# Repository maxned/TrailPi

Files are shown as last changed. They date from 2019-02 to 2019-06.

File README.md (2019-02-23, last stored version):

# TrailPi
ECS 193 Senior Design Project for a DIY Web Cameras Network

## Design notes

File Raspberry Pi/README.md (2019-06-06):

# README

This is the software that is meant to run on the Raspberry Pi.

For a release, save all of these files into a folder called **TrailPi** and zip it. This folder should be saved to the home directory on the Pi.

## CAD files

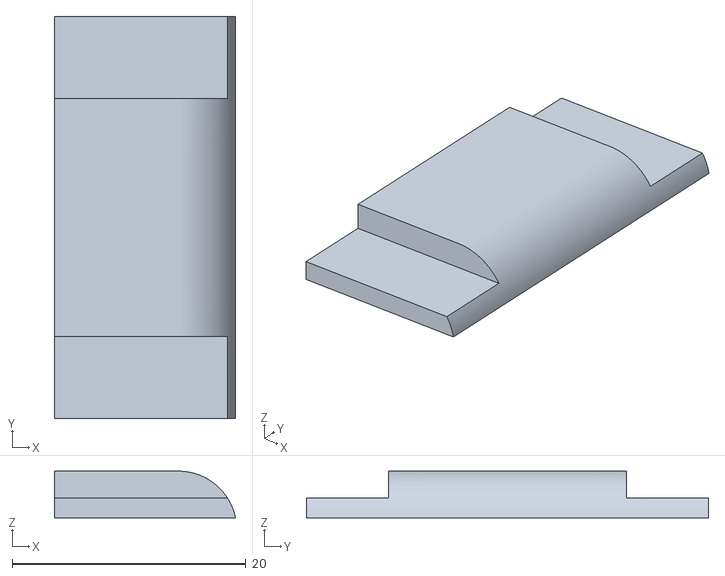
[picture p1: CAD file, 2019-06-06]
3D Printed Components/IR LED Endstop.stl
15.5 x 34.4 x 4.00

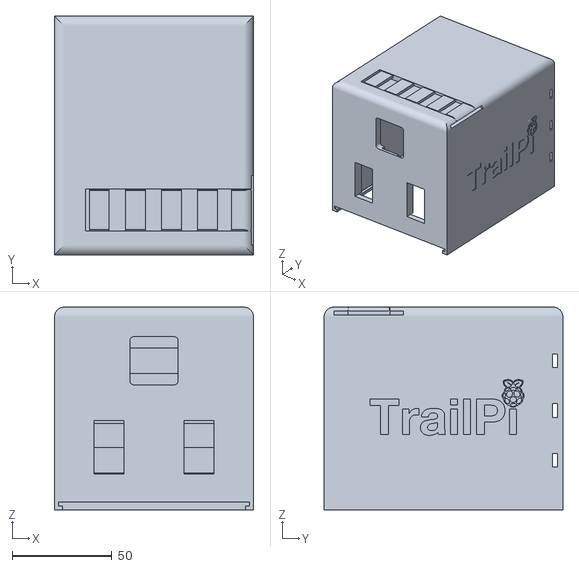
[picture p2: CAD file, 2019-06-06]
3D Printed Components/Enclosure.stl
100.0 x 120.0 x 102.0

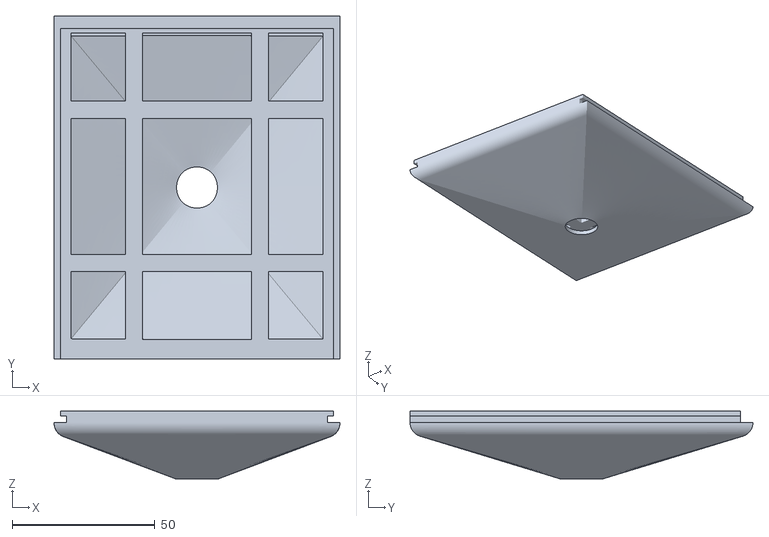
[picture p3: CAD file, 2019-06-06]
3D Printed Components/Bottom Cover.stl
100.0 x 120.0 x 23.7

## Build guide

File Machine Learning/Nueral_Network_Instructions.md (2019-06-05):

# TrailPi
ECS 193 Senior Design Project for a DIY Web Cameras Network

## Image recognition using a 5-layer CNN (Convolutional Neural Network)

### Requirements

To install packages that will work with the CNN model type into the terminal:

     $ pip install -r requirements.txt 

### **Running the Script**
The script used to run:

    $ python test.py

 The script will load in the model and then will ask the user if they want to apply the model on a folder or a single image :

    $ Folder(F) or Single File(S)?: _

### **Choosing Folder(F)**
1. If user selects folder, then the script will check locally if `animals_and_humans` and `nothing` folders already exists, if they don't then it will create them. Then the user is asked to enter the folder name (local to the script) of the images they want to classify:

    $ Folder Name: folder_name_here

2. Hit `Return` and the script will begin sorting the images into their respective folders (`animals_and_humans` or `nothing`).
3. Once complete, the prompt will ask if the user would like to continue and sort other files or folders with the following prompt:

        $ Continue (Y/N): _

4. If user selects `'N'` then the script will terminate, and if the user selects `'Y'` then the script will repeat the steps above asking if the user wants a folder or single file.

### **Choosing Single File(S)**
1. If the user selects single file, then the script will prompt the user to give the name of the image (must be local to the script) as such:

        $ ImageName: my_image.jpg 

2. The script will then print out if the image contains an animal/human or if there is nothing in the image.
3. Once complete, the prompt will ask if the user would like to continue and sort other files or folders with the following prompt:

        $ Continue (Y/N): _ 
4. If user selects `'N'` then the script will terminate, and if the user selects `'Y'` then the script will repeat the steps above asking if the user wants a folder or single file.

## **Retraining the Image Classifier**

1. Ensure that the **requirements** are installed before running the model.
2. Ensure that the script `cnn.py` has  `animals`, `nothing` and `people` folder local to it. The reason the `animals` and `people` folder are kept separate is in case the user may want to modify the classes to determine if its a person or animal instead. 
3. In  a terminal window run:

         $ python cnn.py

4. The script is now creating a new model with the provided images.
5. A `labels.npy` and `trail_pics.pny` file will be created, these are the numpy representation of the images, very useful if later the user decides to use the same images, the user would uncomment the following lines in the `cnn.py` file:

        trail_pics = np.load("trail_pics.npy")
        labels = np.load("labels.npy")
6. Once the neural network is done with it's training and validation, two files will  be created locally named `model.h5` (containing the weights for the model) and `model.json` (containing the actual model).
7. Replace the `model.h5` and `model.json` that are local to the `test.py` and `classifier.py` folder with the new ones generated.
8. The new model will now be used by the `test.py` to make predictions on new images.

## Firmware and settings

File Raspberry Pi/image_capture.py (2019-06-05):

# This script is in charge capturing images and saving them to disk.

# Basic method of operation:
# - Set everything up
# - Indefinitely run the image capture
# - Use signals to pause the image capture when necessary
# - Flags are used to specify what happens in the image capture loop based
#   on different events such as enabling/disabling capture or detected motion.

from picamera import PiCamera
from gpiozero import MotionSensor, DigitalOutputDevice
from datetime import datetime
import helpers
import json
import time
import signal
import io
import os

# Global variables set in main
log = None
config = None
pir_output = None
pir_input = None
relay_output = None
take_picture = False

def set_ir_led_state(state):
    relay_output.value = state
    log.info("IR state set: {}".format(state))

def take_picture(signum, frame):
    log.debug("Signal take picture")

    global take_picture
    take_picture = True

def enable_capture(signum, frame):
    log.info("Signal capture enabled")

    global capture_enabled
    capture_enabled = True

    # Turn on IR LED if it should be on now
    if config["ir_led_always_on"]:
        set_ir_led_state(True)

def disable_capture(signum, frame):
    log.info("Signal capture disabled")

    global capture_enabled
    capture_enabled = False

    # Always turn off LED
    set_ir_led_state(False)

def motion_detected():
    log.info("Motion detected: {}".format(pir_input.value))

    # Mirror the output of the PIR sensor for the other Pi
    pir_output.value = pir_input.value

    if pir_input.value and capture_enabled:
        global take_picture
        take_picture = True

        # If IR LED only on during capture then we need to turn it on
        # because an event just occured
        if not config["ir_led_always_on"]:
            set_ir_led_state(True)

def switch_to_other_camera():
    log.info("Switch to other camera")

    pid = helpers.get_pid("camera_manager.py")
    if pid == 0: # camera_manager isn't running for some reason
        log.warning("camera_manager.py PID not found")
        return

    # Signal to camera_manager.py that the night camera should be enabled and self
    # should be disabled
    os.kill(pid, signal.SIGUSR1)

def save_picture(image, timestamp):
    if image:
        try:
            # Make sure directory exists
            if not "images" in os.listdir():
                os.mkdir("images")

            with open('{}/{}.jpg'.format(config["image_folder"], timestamp), 'wb') as file:
                file.write(image)

                # Make sure file is saved to disk so it can be uploaded
                file.flush()
                os.fsync(file.fileno())

                log.info("Saved image: {}.jpg".format(timestamp))
        except:
            log.error("Failed saving image to disk: {}".format(timestamp))

def begin_image_capture():
    camera = PiCamera(resolution=tuple(config["resolution"]))
    # Encode the site number into the exif field of the image just in case
    camera.exif_tags["EXIF.SubjectDistanceRange"] = str(config["site_number"])
    time.sleep(2) # Give camera time to wake up

    # Goal is keep capturing images and saving images to a buffer
    # When told to take_picture, save the buffered images to disk
    # Then save the current image to disk and the same number of buffered images after

    # Images to save before and after take_picture event
    buffer_size = int(config["capture_chunk_size"] / 2)
    image_buffer = helpers.RingBuffer(buffer_size)
    left_to_save = 0

    stream = io.BytesIO()
    # Quality is not in percentage, it is logarithmic
    # Do not save the thumbnail to keep the file size smaller
    for capture in camera.capture_continuous(stream, format='jpeg',
                                             quality=config["quality"], thumbnail=None):

        log.info("Image Captured")
        log.info("Analog Gain: " + str(float(camera.analog_gain)))
        log.info("Digital Gain: " + str(float(camera.digital_gain)))

        # Timestamp the image
        timestamp = datetime.now().strftime(config["image_timestamp_format"])

        # Event happened so save buffered images and start saving future images
        global take_picture
        if take_picture == True:
            take_picture = False

            # Save buffered images to disk
            for image, im_timestamp in image_buffer.get():
                save_picture(image, im_timestamp)

            # Clear buffered images
            image_buffer.clear()

            # Number of images to save past the take_picture event
            # including the image right after the event
            left_to_save = buffer_size + 1

        if left_to_save > 0:
            # These are the images saved to disk after the take_picture event
            save_picture(stream.getvalue(), timestamp)
            left_to_save -= 1
        else:
            # Save images into buffer if not saving them to disk
            # Save as tuple together with the timestamp
            image_buffer.append((stream.getvalue(), timestamp))

            # If IR LED only on during capture then we are done so turn it off
            if not config["ir_led_always_on"]:
                set_ir_led_state(False)

        # Reset the stream to capture a new image
        stream.seek(0)
        stream.truncate()

        # Switch to the other camera based on the specified thresholds
        if config["camera_type"] == "day" and capture_enabled and \
                camera.analog_gain >= config["day_to_night_analog_threshold"] and \
                camera.digital_gain >= config["day_to_night_digital_threshold"]:
            switch_to_other_camera()
        elif config["camera_type"] == "night" and capture_enabled and \
                camera.analog_gain <= config["night_to_day_analog_threshold"] and \
                camera.digital_gain <= config["night_to_day_digital_threshold"]:
            switch_to_other_camera()

        # Sleep between images (needed to allow auto exposure to work)
        # Values of at least 0.1 will allow camera to expose within 10 seconds
        # Higher values will allow for faster exposure
        time.sleep(config["inter_capture_delay"])

        # If capture is disabled, stop taking pictures and suspend the whole script
        while not capture_enabled:
            signal.pause()

if __name__== "__main__":
    log = helpers.setup_logger(os.path.basename(__file__))
    log.info("Starting execution")

    if os.path.exists("/boot/trailpi_config.json"):
        config_file = "/boot/trailpi_config.json"
    else:
        config_file = "trailpi_config.json"

    config = json.load(open(config_file))

    # Default value for whether image capture should be enabled on start
    # depending on camera_type (day or night)
    if config["camera_type"] == "day":
        capture_enabled = True
    else:
        capture_enabled = False

    # PIR output that mirrors PIR input for use by the other Pi
    pir_output = DigitalOutputDevice(config["pir_output_pin"])

    # PIR connected to GPIO pin
    pir_input = MotionSensor(config["pir_input_pin"])
    pir_input.when_motion = motion_detected
    pir_input.when_no_motion = motion_detected

    # Day camera will not have IR LED connected so we don't have to differentiate
    # turning on the relay between day and night camera with the IR LED
    relay_output = DigitalOutputDevice(config["relay_output_pin"])

    # Set default state of IR LED if it should always be on
    if config["ir_led_always_on"] and capture_enabled:
        set_ir_led_state(True)

    # Manually trigger a take_picture event (only for debug)
    if config["debug"]:
        signal.signal(signal.SIGINT, take_picture)

    # Sign up for signals to control whether capture should be enabled or disabled
    signal.signal(signal.SIGUSR1, enable_capture)
    signal.signal(signal.SIGUSR2, disable_capture)

    # Keep taking pictures but save them only when needed
    begin_image_capture()

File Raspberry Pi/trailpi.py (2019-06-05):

# This script is in charge of running and stopping all of the TrailPi scripts
# and relaunching them if something crashes.

import subprocess
import helpers
import time
import signal
import os

scripts = ["camera_manager.py", "image_capture.py", "image_upload.py", "check_in.py"]

# Kill all scripts including self (useful for debugging)
def kill_everything(signum, frame):
    for script in scripts:
        pid = helpers.get_pid(script)
        if pid != 0:
            os.kill(pid, signal.SIGKILL)
    raise

signal.signal(signal.SIGINT, kill_everything)

# Make sure directory for crashlogs exists
if not "crashlogs" in os.listdir():
    os.mkdir("crashlogs")

# Launch all of the scripts and relaunch them if they crash
while True:
    for script in scripts:
        pid = helpers.get_pid(script)

        # Restart script if it crashed or hasn't been started yet
        if pid == 0:
            ps = subprocess.Popen("python3 {} 2>crashlogs/{}.crashlog &".format(script, script), shell=True)

    # Recheck for crashed scripts every so often
    time.sleep(60)

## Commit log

2019-02-26 Simple server/client building blocks
    Starting scripts for both server and clients, believe client doesn't
    work currently, will be fixed and expanded upon
    <Add> 'client/TrailPiClient.py'
    <Add> 'server/TrailPiServer.py'
2019-02-27 Skeletons for server + client scripts
    Outline scripts for server and client, with functional communication
    Two modes for client connection:
    1) `check_in`, to show camera is active
    2) `new_image`, to transfer a new image to server
    Starts in a testing mode with lots of debugging output to follow steps
    Running:
    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
2019-02-28 Activity tracking implemented
    Server will now handle check-in requests, storing last check-in time in
    a dictionary and logging it in a file
    <Upd> 'client/TrailCamMain.py' - debug output for closing the socket
    <Upd> 'client/Mode1.py' - remove leftover filler message causing issues
    <Upd> 'server/TrailServerMain.py'
    - some changes to recv calls to fix timeout not working
    - utilize the activity tracking logic when appropriate
    - some *more* debugging output
    <Add> 'server/Living.py' - dictionary and function for maintaining the
    activity log
2019-03-01 Handle logging, specific exception, empty message
    Add function to log server requests to a file, target specific
    `socket.timeout` exception, fix the issue of the empty message being
    received.
    <Upd> 'client/Mode0.py' - change `socket.send` to `socket.sendall`
    <Upd> 'client/Mode1.py' - change `socket.send` to `socket.sendall`
    - change `socket.send` to `socket.sendall`
    - implement logging function and call it after getting requests
    - target timeout specific exception before general exceptions
    - more checking on received data and watching the socket
    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
2019-03-07 Use logging module instead of just print() calls
    Adjusted all files for this change
2019-03-12 Further transitioning to flask
    Move more to the flask server/client, also trimmed old code in all
    files
    <Upd> 'client/TrailCamMain' - this script doesn't do much currently
    <Upd> 'client/Mode0' - just sends post request
    <Upd> 'client/Mode1' - just sends post request with image file
    <Upd> 'server/TrailServerMain' - lots of logic added for new setup
    <Upd> 'server/Living' - clean up process
2019-03-13 Streamline files with better names
    No longer need separate files for client modes, provide cleaner api
    calls,
    <Rmv> 'client/Mode0.py' - merged into `client/camera_client_api.py`
    <Rmv> 'client/Mode1.py' - merged into `client/camera_client_api.py`
    <Upd> 'client/camera_client_api.py':
    - file renamed from `client/TrailCamMain`
    - provides api calls `check_in()` and `send_image(file_path)`
    <Upd> 'server/activity.py':
    - file renamed from `server/Living.py`
    - use a more readable timestamp format
    <Upd> 'server/trail_pi_server.py':
    - file renamed from `server/TrailServerMain.py`
    - remove '/' `Hello World` route
    - adjust for modified camera requests data struc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
2019-03-13 Check_in working, working on image_transfer
    Misc changes such as global stuff moved back to top of files
    <Upd> 'client/camera_client_api.py' - added a testing function
    - DB connection commented for now
    - `check_in` is fully functional
    - working on `image_transfer` request handling
    - image saving to filesystem/DB commented until transfer is
    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
2019-03-28 Initial Pi camera taking pictures with triggering on pixel change
2019-03-31 Add PIR sensor script
2019-03-31 Add code for triggering relay
2019-04-02 added all cameras to the map
2019-04-03 added route for listing all objects in S3 bucket
2019-04-06 Remove unneeded test files for relay and pir
2019-04-07 Add script to check in the device to the server every 30 min
2019-04-16 Rename movement camera config
2019-04-16 Add better exception handling so that things would not just crash
    [check_in.py, image_upload.py, trailpi.py]
2019-04-17 First pass at database integration
    Should be mostly set up, just need a way to test it.
    <Mod> 'sever/application.py':
    - changed imports
    - removed some antiquated code from before using aws
    - insert received pictures to the db
    <New> 'sever/application/__init__.py' - config + module identification
    <New> 'sever/application/models.py' - represents the tables in the db
    <Del> 'sever/config.py' - no longer needed
    <New> 'server/first_time_create_db.py' - provides a script to run for
    first-time setup of the database's tables (don't run once set up)
    <Mod> 'server/requirements.txt' - updated with requirements for flask +
    SQLAlchemy
2019-04-23 Make sure scripts dont crash when the image folder is missing
    [image_upload.py, trailpi.py]
2019-04-23 Remove outdated movement camera
2019-04-25 Add ability for a script to signal capture enable/disable from the camera
2019-04-26 Add inter-capture delay (for auto exp.) and exposure switching to diff. camera
2019-04-27 Fix bug when checking for trailpi script running
    [image_capture.py]
2019-04-27 Mirror PIR input to an output pin for use by other Pi
2019-05-01 added select for cameras
2019-05-01 modified image retrieval route to filter based on camera selection
2019-05-01 finished first iteration of filtering by camera
2019-05-10 Add support for the IR LED either always on or turn on during an event
2019-05-12 Improvements to config and improvement for IR LED initial state
2019-05-12 Add digital gain as a threshold so the camera could switch when it gets darker
2019-05-15 Add error logging to the scripts and edit a couple comments
    [image_upload.py]
2019-05-17 Add easy scripts to run TrailPi or a live camera feed
2019-05-18 Rename many things, slightly tweak camera_manager operation, and add comments to all scripts
2019-05-22 Change relay type for IR LED
2019-05-22 Change relay output pin
2019-05-29 addded update printout so user knows what the cnn.py is doing
2019-05-31 Update relay output pin
2019-06-06 Add README to Raspberry Pi
2019-06-06 Add 3D printed components for the camera module
    [Bottom Cover.stl, Enclosure.stl, IR LED Endstop.stl]
2019-06-07 Send site number as string for check-in to properly track the state of the Pi on the website
2019-06-21 Update wiring diagram for 3V relay instead of 5V
2019-06-27 Fix mistake in wiring the IR LED relay
